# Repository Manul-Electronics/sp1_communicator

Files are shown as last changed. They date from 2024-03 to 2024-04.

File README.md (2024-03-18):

# P1 Wireless Interface (P1WI)
Smart Meter serial to wireless interface (Wi-Fi).

## Configuration
1. Plug a USB-C cable in the USB-C port of the P1WI.
2. Connect the other end of the cable to your PC.
3. Start the **P1WI Utility** program and click on **Start the configuration** button. This action will start the configuration wizard.
4. When prompted to do it, select the Wi-Fi network on which the P1WI should connect. If your Wi-Fi network does not pop in the list, please verify that it operates at 2.4GHz as 5.0GHz network are not supported by the ESP32 series.
5. Once the Wi-Fi network is selected, enter you Wi-Fi password into the textbox. By default, the text is obscucated, click on **Reveal passphrase** to make it appear.
6. Click on **Next**. The P1WI should now try to connect to your network. If connection is successfuly established, the program will allow you to go to the next step. In case of failure at this step, please double check your Wi-Fi password and check that P1WI is close enough of your Wi-Fi router (the network symbol should be as full as possible).
7. The configuration is now completed and the **P1WI Utility** program should display the following message : *Configuration completed successfuly. You can now disconnect the P1WI from your computer.*
8. After you unplugged it from your computer, take the RJ11 cable and connect it to the P1 Port of your Smart Energy Meter. To do this, lift up the green/yellow cover of your Smart Energy Meter and plug it in.
9. Connect the other end of the cable to you P1WI. A red light should have been lightning up, indicating that the module is powered by the Smart Energy Meter, once connected onto your Wi-Fi, a green/yellow LED should also have been lightning up. If the connection failed, a second red LED will light up.
10. If everything went well, you can now use your P1WI.

## How to use it?

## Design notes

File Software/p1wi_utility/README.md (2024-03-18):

# p1wi_utility

A new Flutter project.

## Getting Started

This project is a starting point for a Flutter application.

A few resources to get you started if this is your first Flutter project:

- [Lab: Write your first Flutter app](https://docs.flutter.dev/get-started/codelab)
- [Cookbook: Useful Flutter samples](https://docs.flutter.dev/cookbook)

For help getting started with Flutter development, view the
[online documentation](https://docs.flutter.dev/), which offers tutorials,
samples, guidance on mobile development, and a full API reference.

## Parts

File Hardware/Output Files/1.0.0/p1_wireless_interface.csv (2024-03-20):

Reference | Value | MPN | internalRef | Qty
C1, C3 | 10uF | 0402ZD106MAT2A | 1.03.011 | 2
C2, C8, C9, C12 | 100nF | 885012205037 | 1.03.019 | 4
C4, C5 | 10uF | 875115644009 | 1.01.003 | 2
C6, C7 | 22uF | 885012109014 | 1.03.021 | 2
C10, C11 | TBD |  |  | 2
D1 | 82400102 | 82400102 | 31.01.001 | 1
D2, D3 | 1N5819W | 1N5819HW-7-F | 4.02.001 | 2
D4 | WS2812C-2020 | WS2812C-2020 | 8.02.002 | 1
D5 | PWR | 150040RS73240 | 8.03.007 | 1
J1 | 615006138421 | 615006138421 | 2.16.003 | 1
J2 | 629722000214 | 629722000214 | 2.12.009 | 1
L1 | 1uH | 7447730 | 14.00.001 | 1
R1, R4, R8, R9, R12 | 10K | CRCW040210K0FKEDHP | 12.02.010 | 5
R2 | 1M | CRCW04021M00DHEDP | 12.02.027 | 1
R3 | 1K | CRCW04021K00DHEDP | 12.02.026 | 1
R5, R10, R11, R15 | 220R | CRCW0402220RFKED | 12.02.008 | 4
R6, R7 | 5.1K | CRCW04025K10FKED | 12.02.006 | 2
R13, R14 | 0R | RC0402JR-070RL | 12.02.025 | 2
SW1, SW2 | KSEM31JLFS | KSEM31JLFS | 17.02.005 | 2
U1, U2 | 140357145100 | 140357145100 | 8.04.001 | 2
U3 | 173950336 | 173950336 | 10.02.001 | 1
U4 | ESP32-C3-WROOM-02-N4 | ESP32-C3-WROOM-02-N4 | 28.01.007 | 1

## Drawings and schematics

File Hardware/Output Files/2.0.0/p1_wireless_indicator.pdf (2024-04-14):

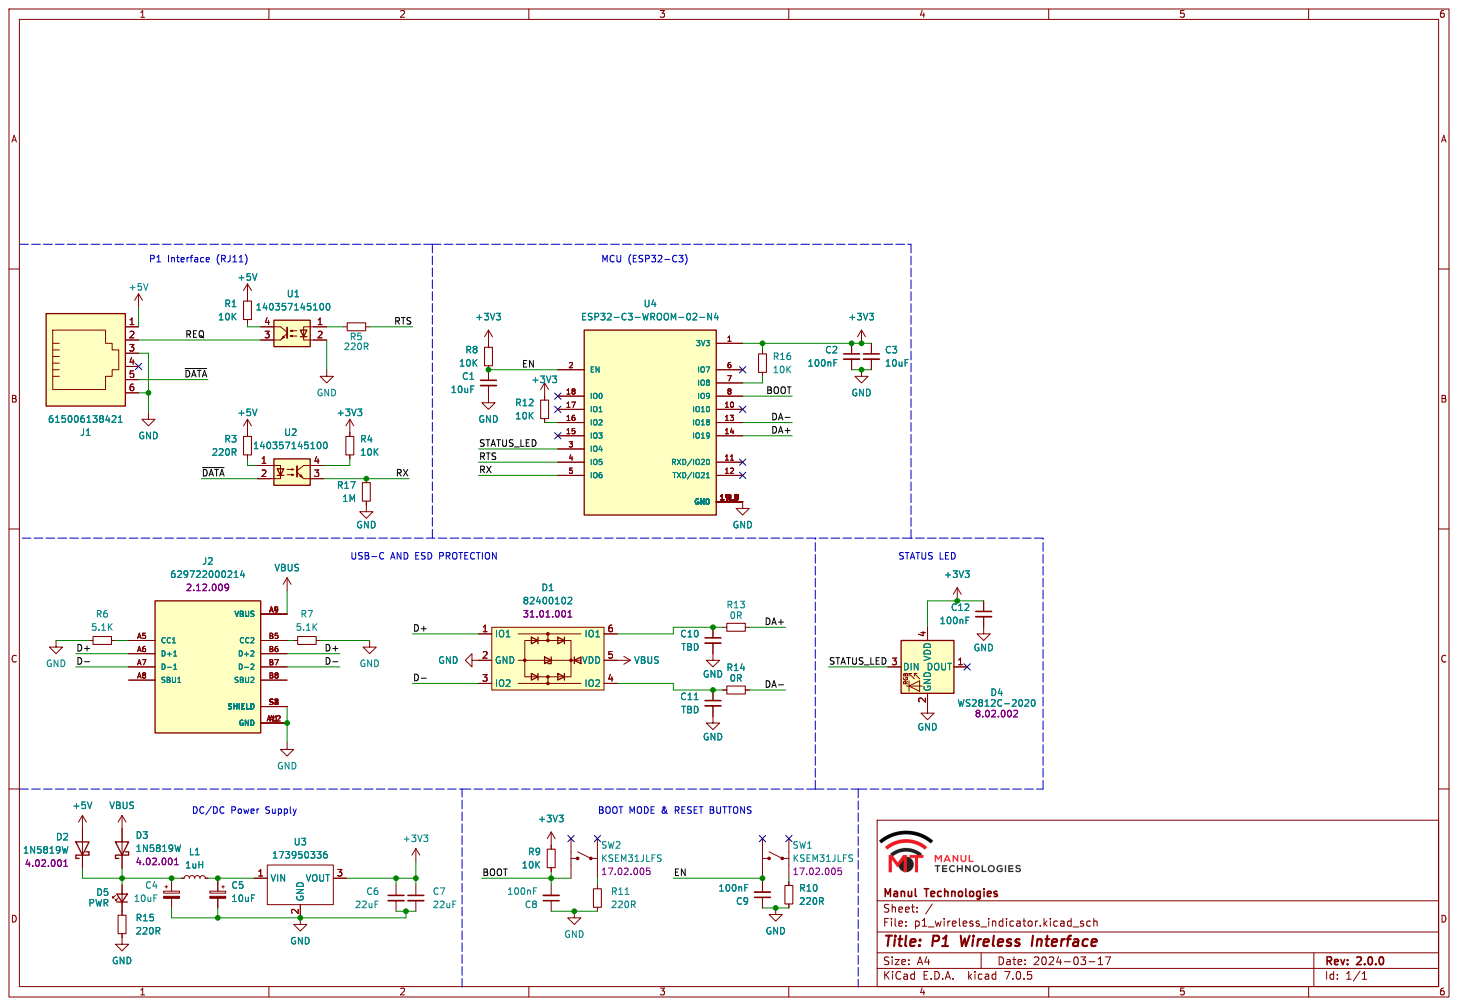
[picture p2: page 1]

File: p1_wireless_indicator.kicad_sch Sheet: / Manul Technologies VBUS D3

Id: 1/1 Title: P1 Wireless Interface

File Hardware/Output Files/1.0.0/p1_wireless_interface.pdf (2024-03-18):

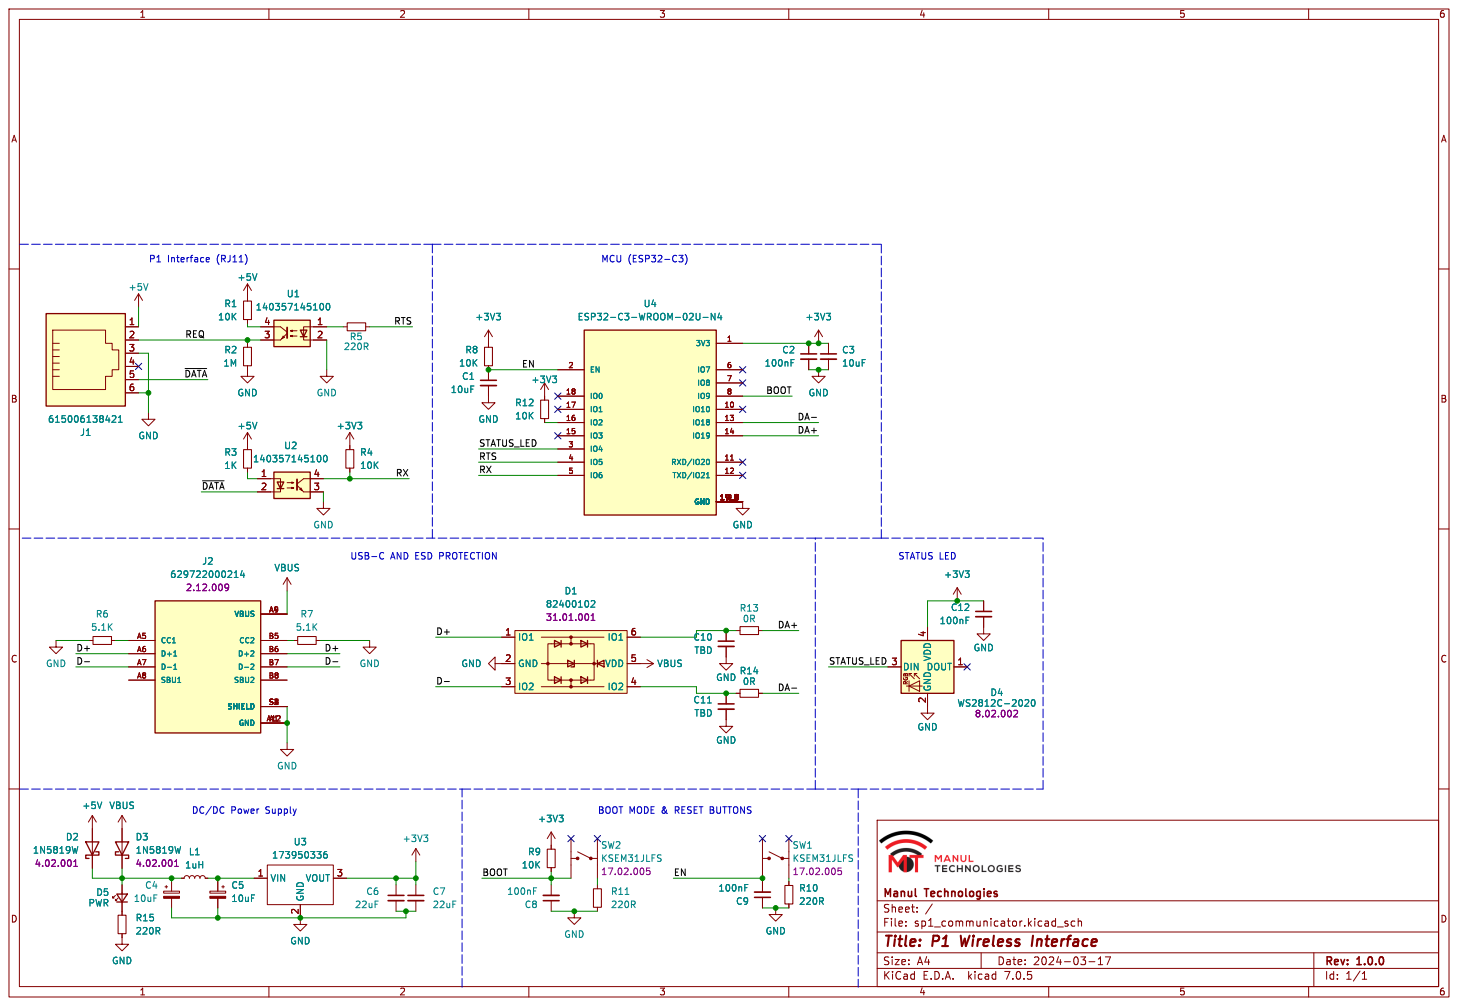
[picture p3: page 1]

File: sp1_communicator.kicad_sch Sheet: / Manul Technologies

Id: 1/1 Title: P1 Wireless Interface

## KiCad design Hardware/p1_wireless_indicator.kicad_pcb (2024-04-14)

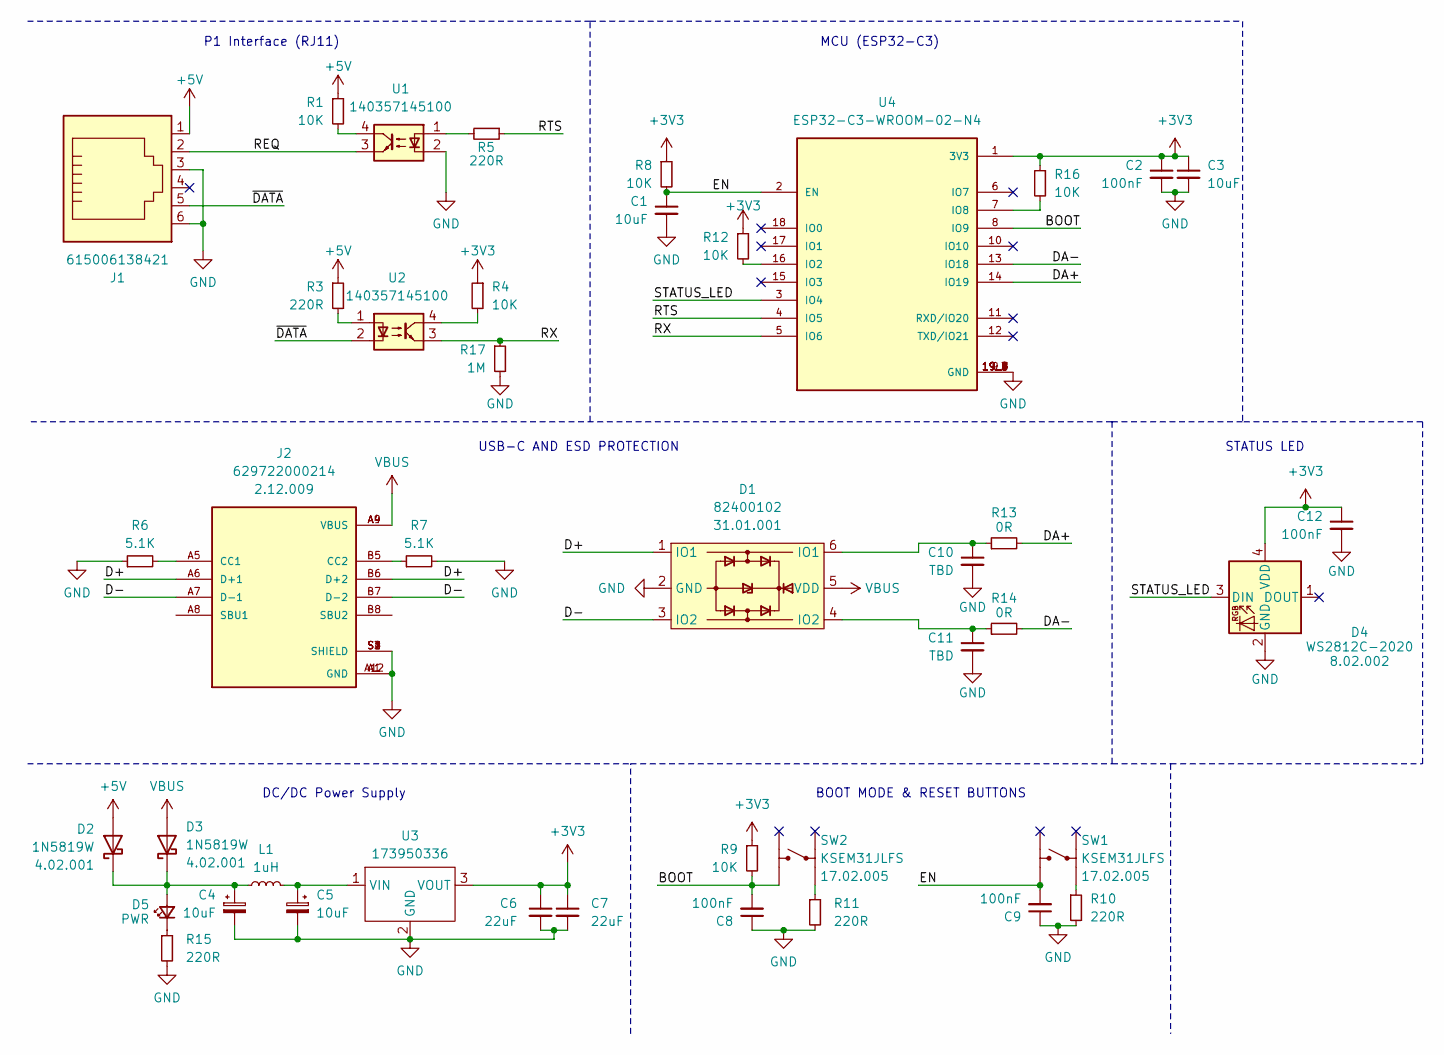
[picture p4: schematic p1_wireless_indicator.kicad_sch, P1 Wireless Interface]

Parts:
C1, C3: 10uF; C_0402_1005Metric; MPN 0402ZD106MAT2A
C2, C8, C9, C12: 100nF; C_0402_1005Metric; MPN 885012205037
C4, C5: 10uF; CP_Elec_6.3x5.7; MPN 875115644009
C6, C7: 22uF; C_1210_3225Metric; MPN 885012109014
C10, C11: TBD; C_0402_1005Metric
D1: 82400102; SOT-23-6; MPN 82400102
D2, D3: 1N5819W; D_SOD-123; MPN 1N5819HW-7-F
D4: WS2812C-2020; LED_WS2812C-2020; MPN WS2812C-2020
D5: PWR; LED_0402_1005Metric; MPN 150040RS73240
J1: 615006138421; MPN 615006138421
J2: 629722000214; MPN 629722000214
L1: 1uH; 7447730; MPN 7447730
R1, R4, R8, R9, R12, R16: 10K; R_0402_1005Metric; MPN CRCW040210K0FKEDHP
R3, R5, R10, R11, R15: 220R; R_0402_1005Metric; MPN CRCW0402220RFKED
R6, R7: 5.1K; R_0402_1005Metric; MPN CRCW04025K10FKED
R13, R14: 0R; R_0402_1005Metric; MPN RC0402JR-070RL
R17: 1M; R_0402_1005Metric; MPN CRCW04021M00DHEDP
SW1, SW2: KSEM31JLFS; MPN KSEM31JLFS
U1, U2: 140357145100; MPN 140357145100
U3: 173950336; SIP3_11.6x8.5mm; MPN 173950336
U4: ESP32-C3-WROOM-02-N4; MODULE_ESP32-C3-WROOM-02-H4; MPN ESP32-C3-WROOM-02-N4

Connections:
+3V3: C2.1, C3.1, C6.1, C7.1, C12.1, D4.4 (VDD), R4.1, R8.1, R9.1, R12.1, R16.1, U3.3 (VOUT), U4.1 (3V3)
+5V: D2.2 (A), J1.1, R1.1, R3.1
/BOOT: C8.2, R9.2, SW2.1, U4.8 (IO9)
/D+: D1.1 (IO1), J2.A6 (D+1), J2.B6 (D+2)
/D-: D1.3 (IO2), J2.A7 (D-1), J2.B7 (D-2)
/DA+: R13.2, U4.14 (IO19)
/DA-: R14.2, U4.13 (IO18)
/EN: C1.1, C9.2, R8.2, SW1.1, U4.2 (EN)
/REQ: J1.2, U1.3
/RTS: R5.1, U4.4 (IO5)
/RX: R17.1, U2.3, U4.5 (IO6)
/STATUS_LED: D4.3 (DIN), U4.3 (IO4)
/~DATA: J1.5, U2.2
GND: C1.2, C2.2, C3.2, C4.2, C5.2, C6.2, C7.2, C8.1, C9.1, C10.2, C11.2, C12.2, D1.2 (GND), D4.2 (GND), J1.3, J1.6, J2.A1 (GND), J2.A12 (GND), J2.S1 (SHIELD), J2.S2 (SHIELD), J2.S3 (SHIELD), J2.S4 (SHIELD), R6.1, R7.2, R10.2, R11.2, R15.2, R17.2, U1.2, U3.2 (GND), U4.9 (GND), U4.19_1 (GND), U4.19_2 (GND), U4.19_3 (GND), U4.19_4 (GND), U4.19_5 (GND), U4.19_6 (GND), U4.19_7 (GND), U4.19_8 (GND), U4.19_9 (GND)
unnamed: C10.1, D1.6 (IO1), R13.1
unnamed: C11.1, D1.4 (IO2), R14.1
unnamed: C4.1, D2.1 (K), D3.1 (K), D5.2 (A), L1.1
unnamed: D5.1 (K), R15.1
unnamed: J2.A5 (CC1), R6.2
unnamed: J2.B5 (CC2), R7.1
unnamed: R1.2, U1.4
unnamed: R3.2, U2.1
unnamed: R4.2, U2.4
unnamed: R5.2, U1.1
unnamed: R10.1, SW1.3
unnamed: R11.1, SW2.3
unnamed: C5.1, L1.2, U3.1 (VIN)
unnamed: R12.2, U4.16 (IO2)
unnamed: R16.2, U4.7 (IO8)
VBUS: D1.5 (VDD), D3.2 (A), J2.A4 (VBUS), J2.A9 (VBUS)

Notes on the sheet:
P1 Interface (RJ11)
MCU (ESP32-C3)
STATUS LED
DC/DC Power Supply
BOOT MODE & RESET BUTTONS
USB-C AND ESD PROTECTION

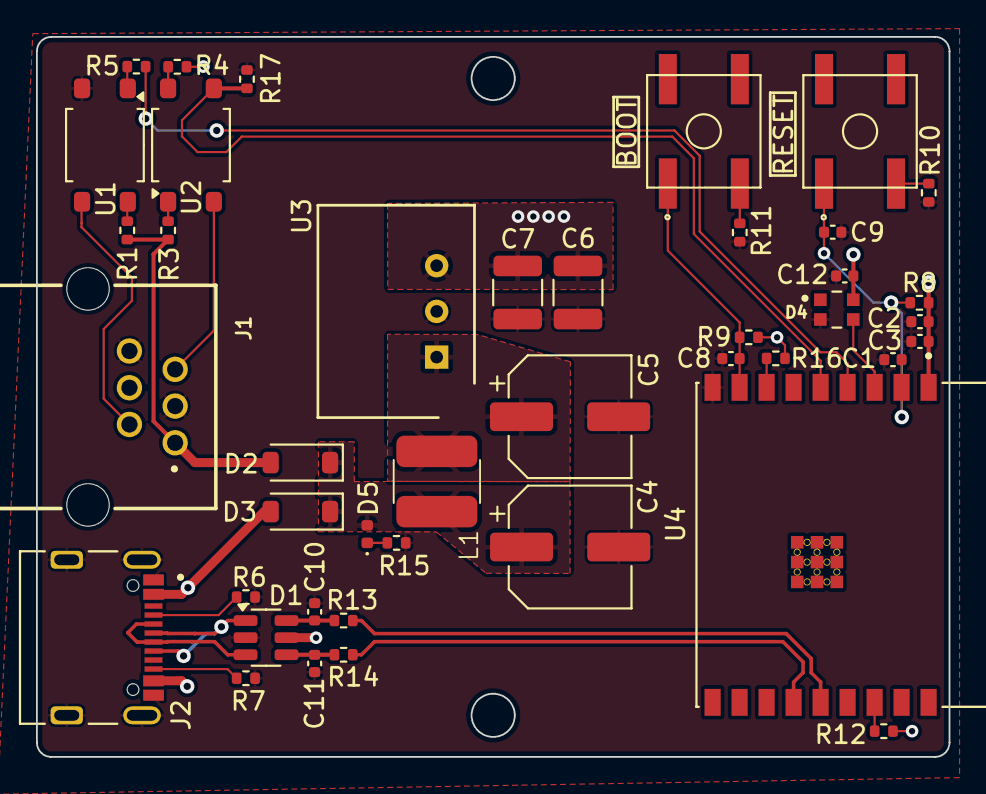
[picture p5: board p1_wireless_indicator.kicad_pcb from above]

Board: 4 copper layers, 50.7 x 40.0 mm, 42 parts (0 on the bottom side), 30 nets.

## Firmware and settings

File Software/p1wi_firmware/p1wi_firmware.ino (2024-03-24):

#include <WiFi.h>
#include <Preferences.h>
#include <Adafruit_NeoPixel.h>

#define STATUS_LED_PIN 4
#define RTS_PIN 5
#define DSMR_TX 6
#define SLEEP_TIME_MS 600000

Adafruit_NeoPixel status_led(1, STATUS_LED_PIN, NEO_GRB + NEO_KHZ800);
Preferences prefs;

bool isUSBConnected = false;
bool isWLConnected = false;

typedef enum {
  IDLE,
  CONFIG,
  SETUP,
  WIFI_CONFIG,
  WIFI_CONFIG_DONE,
  READ_DATA,
} PGM_STATE;

PGM_STATE currentState = IDLE;

int checkUSB(void){
    uint32_t *aa = USB_SERIAL_JTAG_FRAM_NUM_REG;
    uint32_t first = *aa;
    vTaskDelay(pdMS_TO_TICKS(10));
    return (int) (*aa - first);
}

void WiFiEvent(WiFiEvent_t event){
  switch (event) {
      case ARDUINO_EVENT_WIFI_SCAN_DONE:
          Serial.println("Completed scan for access points");
          break;
      case ARDUINO_EVENT_WIFI_STA_START:
          Serial.println("WiFi client started");
          break;
      case ARDUINO_EVENT_WIFI_STA_STOP:
          Serial.println("WiFi clients stopped");
          break;
      case ARDUINO_EVENT_WIFI_STA_CONNECTED:
          Serial.println("Connected to access point");
          break;
      case ARDUINO_EVENT_WIFI_STA_DISCONNECTED:
          Serial.println("Disconnected from WiFi access point");
          break;
      case ARDUINO_EVENT_WIFI_STA_GOT_IP:
          Serial.print("Obtained IP address: ");
          Serial.println(WiFi.localIP());
          break;
      default:
        break;
  }  
}

void setup() {
  if(checkUSB() > 0){
    isUSBConnected = true;
    Serial.begin(115200); 
    currentState = CONFIG;   
  }
  else{
    currentState = WIFI_CONFIG_DONE;
  }
  
  Serial1.begin(115200, SERIAL_8N1, DSMR_TX, -1, false, 11000UL);
  status_led.begin();
  pinMode(RTS_PIN, OUTPUT);
  digitalWrite(RTS_PIN, LOW);
  prefs.begin("sys");
}

void loop() { 
  switch(currentState){
    case CONFIG:
      if(Serial.available() > 0){
        String rawCommand = Serial.readStringUntil('\n');

        String cmd = rawCommand.substring(0, rawCommand.indexOf(' '));
        String arg = rawCommand.substring(rawCommand.indexOf(' '), rawCommand.length());

        if(cmd == "set_ssid"){
          if(arg != ""){
            prefs.putString("ssid", arg);
            if(prefs.getString("ssid", "") == arg){
              Serial.printf("INF/set_ssid/OK");
            }
            else{
              Serial.printf("ERR/could_not_set_properties");
            }            
          }
          else{
            Serial.println("ERR/empty_arg");
          }
        }
        else if(cmd == "set_passphrase"){
          if(arg != ""){
            prefs.putString("pwd", arg);
            if(prefs.getString("pwd", "") == arg){
              Serial.printf("INF/set_passphrase/OK");
            }
            else{
              Serial.printf("ERR/could_not_set_properties");
            }
          }
          else{
            Serial.println("ERR/empty_arg");            
          }
        }
        else if(cmd == "get_network"){
          Serial.printf("INF/registered_network/%s", prefs.getString("ssid","null"));
        }
        else{
            Serial.println("ERR/unknown_command");          
        }
      }
      break;
    case WIFI_CONFIG:
      WiFi.mode(WIFI_STA);
      break;

    case READ_DATA:
      break;

    case IDLE;
  }
}

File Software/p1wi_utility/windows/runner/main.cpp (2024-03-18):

#include <flutter/dart_project.h>
#include <flutter/flutter_view_controller.h>
#include <windows.h>

#include "flutter_window.h"
#include "utils.h"

int APIENTRY wWinMain(_In_ HINSTANCE instance, _In_opt_ HINSTANCE prev,
                      _In_ wchar_t *command_line, _In_ int show_command) {
  // Attach to console when present (e.g., 'flutter run') or create a
  // new console when running with a debugger.
  if (!::AttachConsole(ATTACH_PARENT_PROCESS) && ::IsDebuggerPresent()) {
    CreateAndAttachConsole();
  }

  // Initialize COM, so that it is available for use in the library and/or
  // plugins.
  ::CoInitializeEx(nullptr, COINIT_APARTMENTTHREADED);

  flutter::DartProject project(L"data");

  std::vector<std::string> command_line_arguments =
      GetCommandLineArguments();

  project.set_dart_entrypoint_arguments(std::move(command_line_arguments));

  FlutterWindow window(project);
  Win32Window::Point origin(10, 10);
  Win32Window::Size size(1280, 720);
  if (!window.Create(L"p1wi_utility", origin, size)) {
    return EXIT_FAILURE;
  }
  window.SetQuitOnClose(true);

  ::MSG msg;
  while (::GetMessage(&msg, nullptr, 0, 0)) {
    ::TranslateMessage(&msg);
    ::DispatchMessage(&msg);
  }

  ::CoUninitialize();
  return EXIT_SUCCESS;
}

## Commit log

2022-10-20 Added KiCAD 6.0 project
    [cpu.kicad_sch, interface.kicad_sch, prog.kicad_sch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]
2024-03-14 Rebuild p1_reader project
    [cpu.kicad_sch, interface.kicad_sch, psu.kicad_sch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]
2024-03-16 Resumed schematic
    [cpu.kicad_sch, interface.kicad_sch, sp1_communicator.kicad_sch]
2024-03-16 Schematic completed, started placing
    [cpu.kicad_sch, interface.kicad_sch, psu.kicad_sch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]
2024-03-17 Completed routing
    [cpu.kicad_sch, sp1_communicator.kicad_pcb]
2024-03-18 Added status led and power led and mounting holes
    [sp1_communicator.kicad_pcb, sp1_communicator.kicad_sch]
2024-03-20 Added missing internal references
    [sp1_communicator.kicad_sch]
2024-03-20 Added BOM
    [p1_wireless_interface.csv, sp1_communicator.kicad_pcb]
2024-03-21 Changed name of file
    [p1_wireless_indicator.kicad_pcb, p1_wireless_indicator.kicad_sch]
2024-03-24 Updated Layout
    [p1_wireless_indicator.kicad_pcb, p1_wireless_indicator.kicad_sch]
2024-04-02 Added 10K resistor on GPIO8 to fix boot issue
    [p1_wireless_indicator.kicad_pcb, p1_wireless_indicator.kicad_sch]
2024-04-14 Rounting of V2.0
    [p1_wireless_indicator.kicad_pcb, p1_wireless_indicator.kicad_sch]
2024-05-20 Added bom for v2.0
